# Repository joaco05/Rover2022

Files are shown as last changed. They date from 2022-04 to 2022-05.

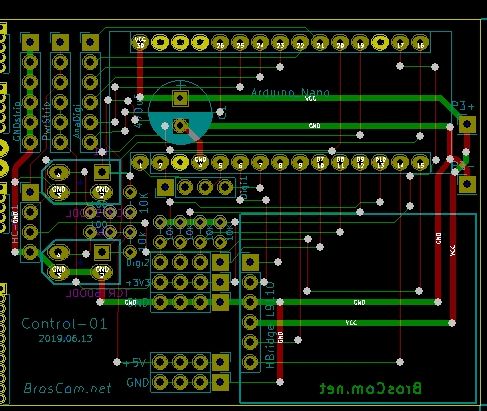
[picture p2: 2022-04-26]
Electronica/ControlPCBs.jpg

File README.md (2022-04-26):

# Rover2022
Rover para clases iniciales. Cerrado y compacto para evitar desconexiones y problemas electricos. Basado en placa Controladora PCB BC2019 (Arduino Nano, driver motores, sensor ultrasonico, sensores IR, conectores) Alimentacion 2 x 3,7V (alimentacion del driver de motores, independiente de Arduino)<br><br>
<b>Printer 3D</b>
Se imprime sin soportes, altura 0,20 o 0,25. Solo las ruedas quedan mejor en modo VASE

<br><br>
<b>ARMADO</b>
El pack de baterias debe ubicarse lo mas adelante posible. Los soportes de motor deberan ir justo despues del borde curvo del chassis, de manera tal que el eje del motor quede al menos 10mm detras del borde.
Esto apunta a que el centro de gravedad se desplace mas cerca de los ejes permitiendo una mejor traccion y evitando patinada de ruedas.

capture_001_20042022_145945

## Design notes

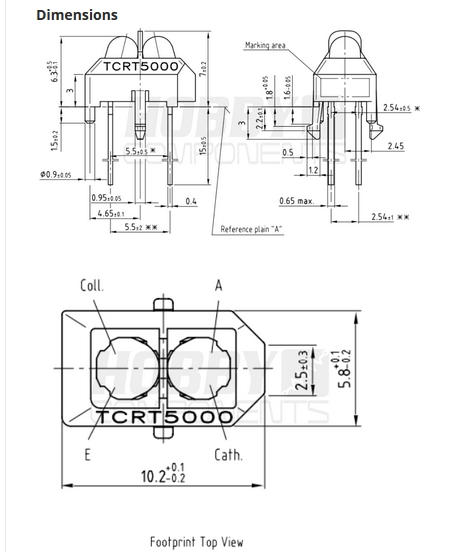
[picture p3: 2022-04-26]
Electronica/VistasTCRT500.jpg

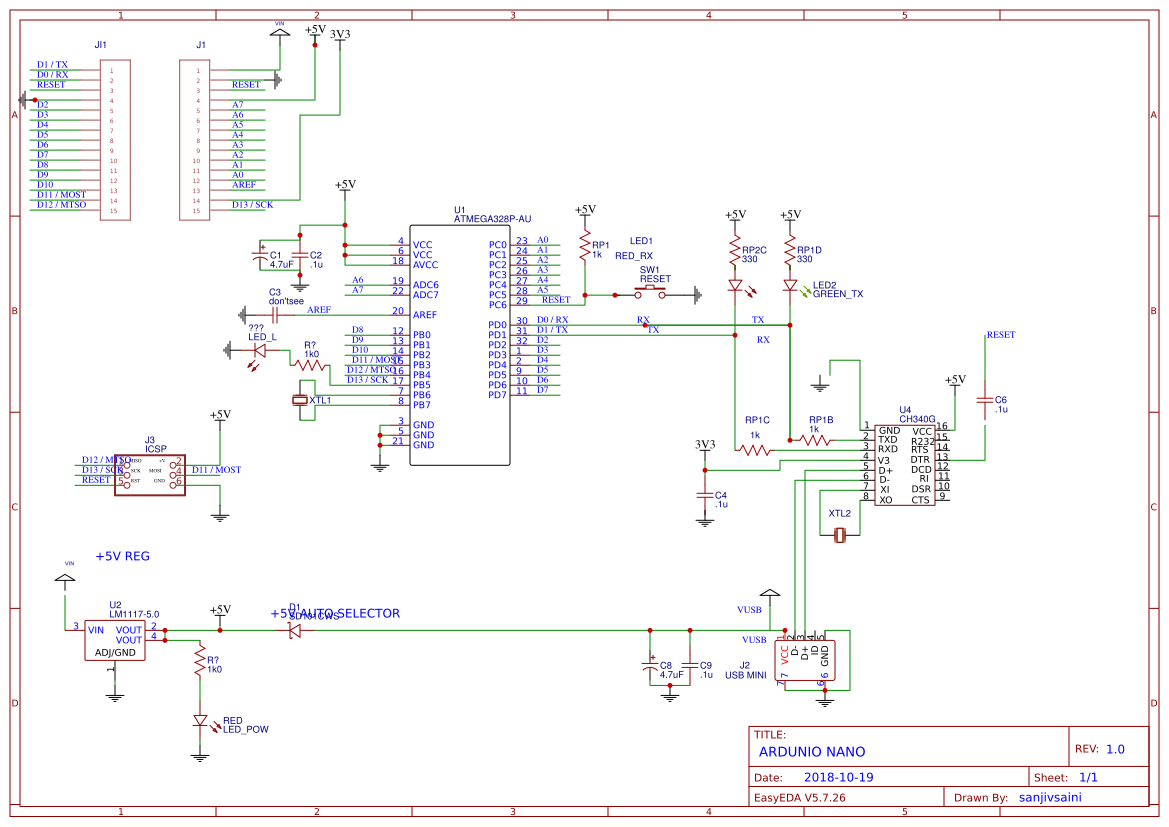
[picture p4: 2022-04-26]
Electronica/ArduinoNanoSch.png

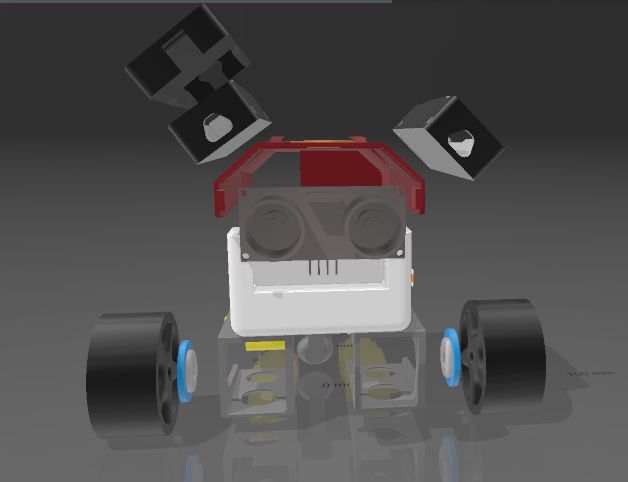
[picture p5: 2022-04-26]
Despiece/capture_002_17042022_132444.jpg

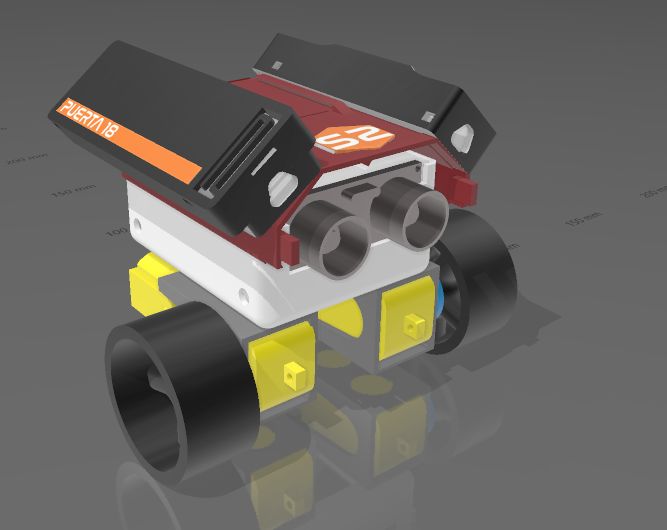
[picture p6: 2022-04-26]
Despiece/capture_001_20042022_145945.jpg

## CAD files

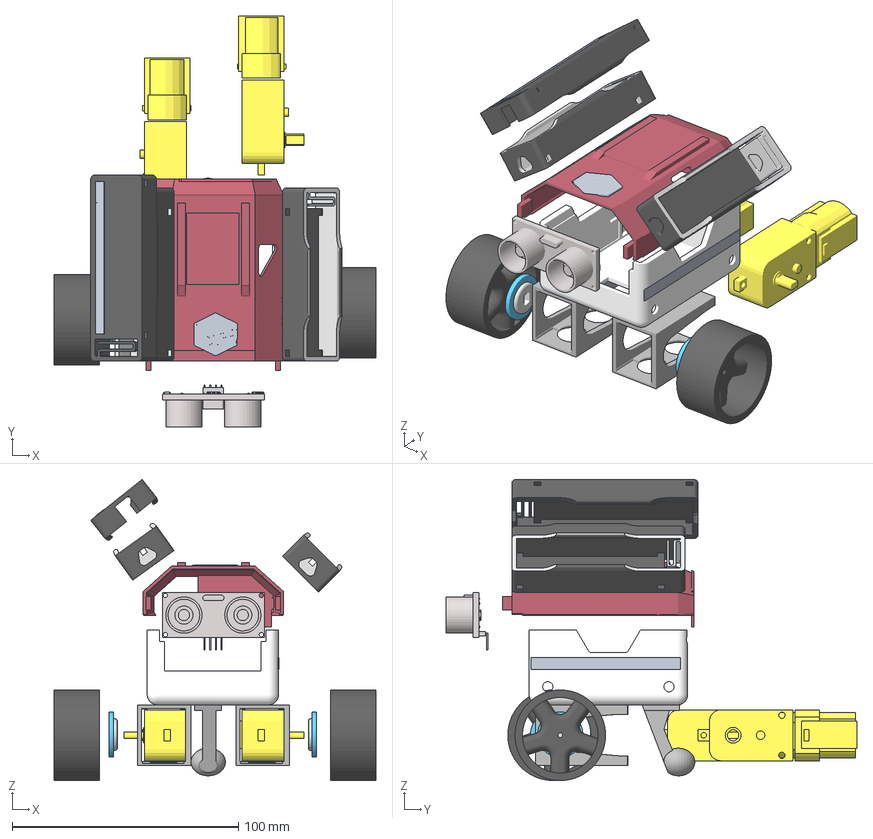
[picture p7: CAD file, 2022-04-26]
3D/SMARSRover2022exploded.3mf
142.1 x 181.5 x 133.0 mm

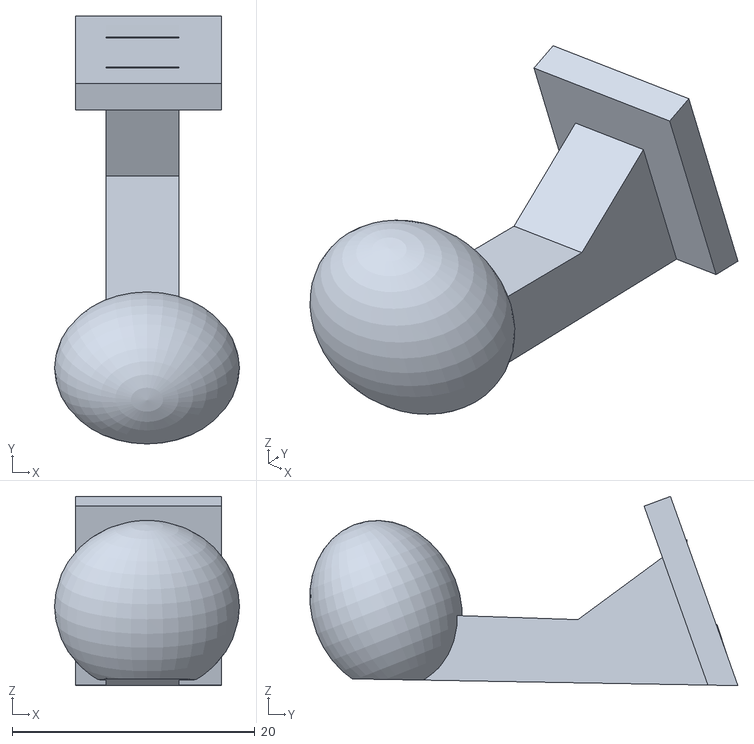
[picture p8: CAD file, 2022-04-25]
3D/STL/PatinCola2.stl
15.2 x 35.3 x 15.6

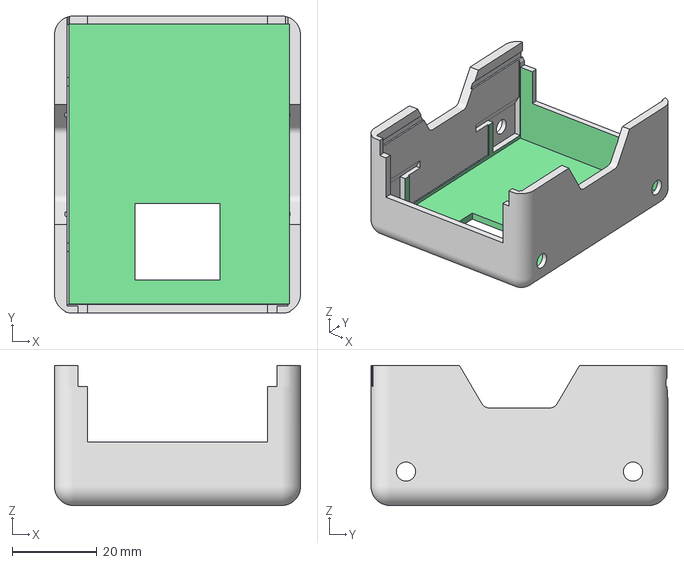
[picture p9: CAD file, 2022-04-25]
3D/2022chassis.3mf
58.0 x 70.0 x 33.0 mm

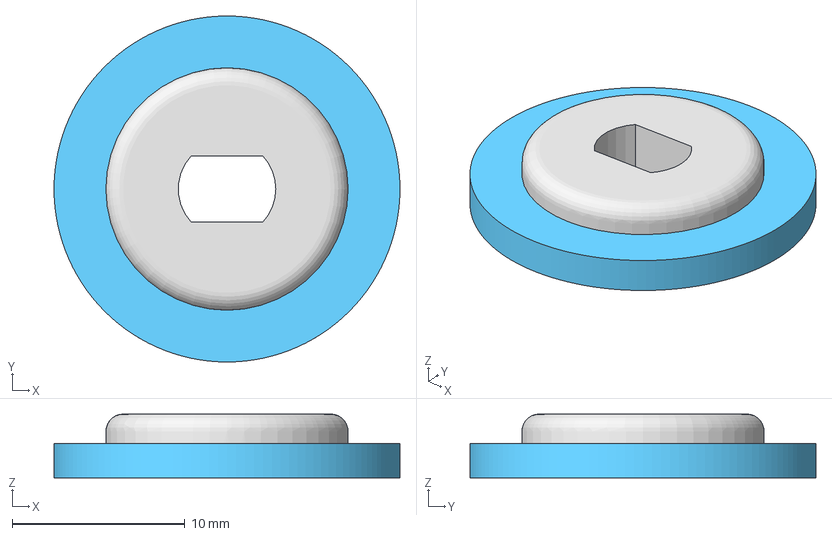
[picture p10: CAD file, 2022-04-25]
3D/TT_Motor_Hub.3mf
20.0 x 20.0 x 3.70 mm

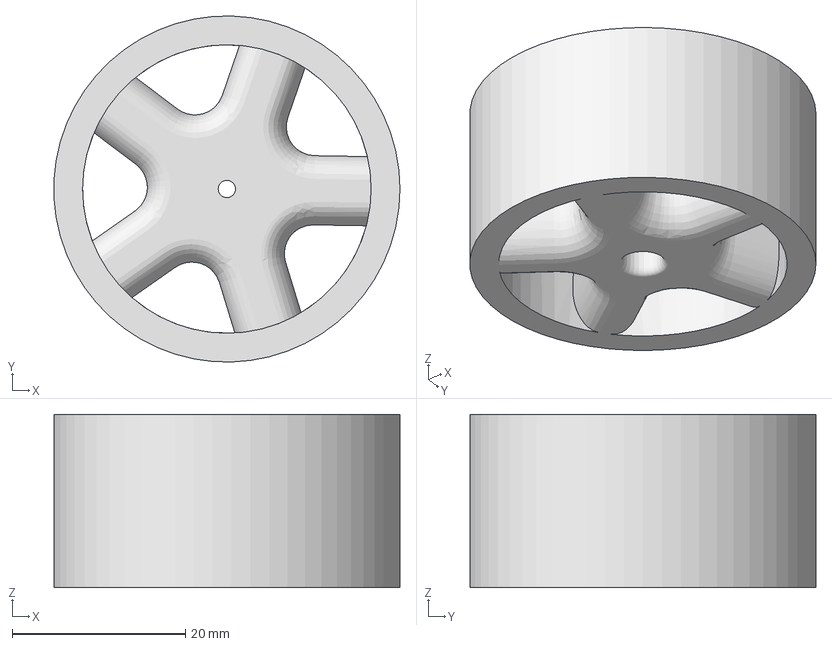
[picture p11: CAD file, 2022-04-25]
3D/Wheel_Rim_40x20mm.3mf
40.0 x 40.0 x 20.0 mm

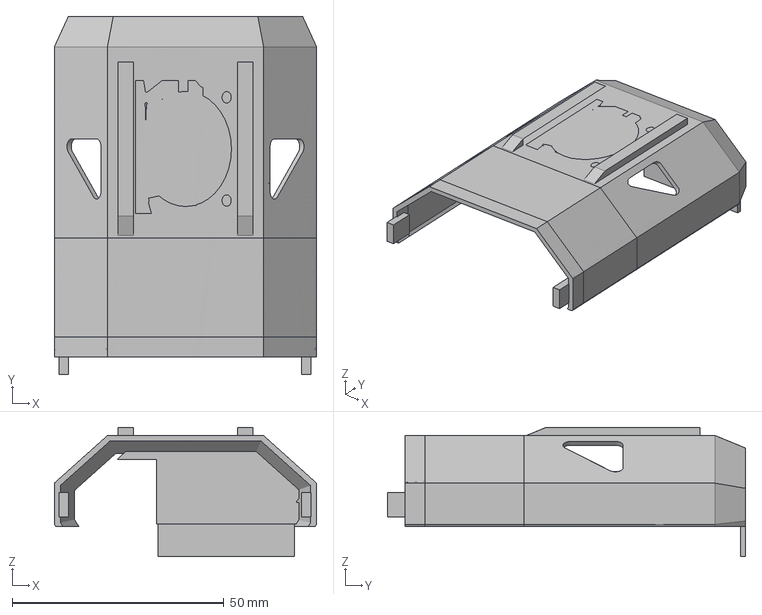
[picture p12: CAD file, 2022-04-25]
3D/SMARSRoverCabina2022a.3mf
62.0 x 84.6 x 30.6 mm

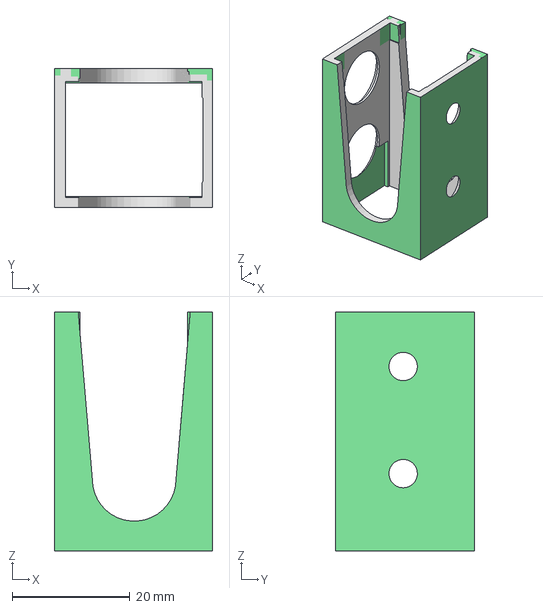
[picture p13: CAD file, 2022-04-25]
3D/2022MotorMount.3mf
26.9 x 23.6 x 40.6 mm

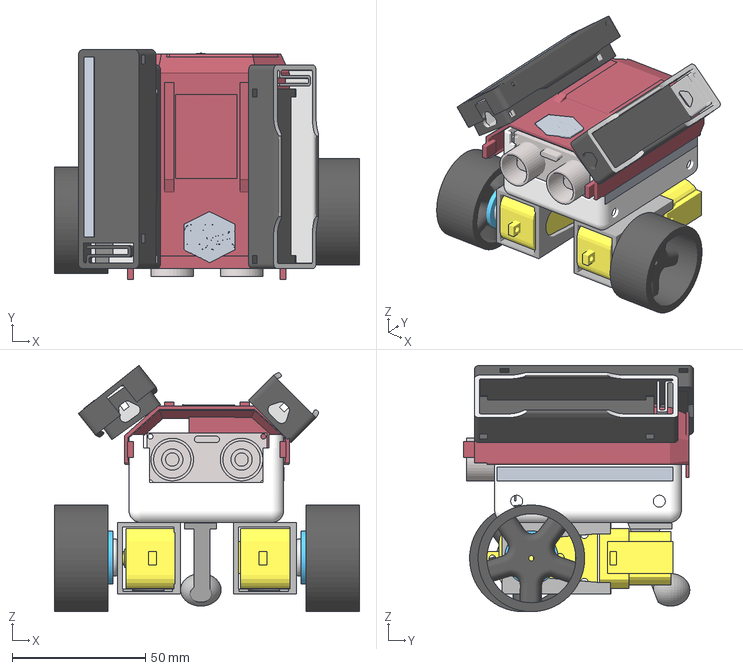
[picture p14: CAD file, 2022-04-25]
3D/SMARSRover2022.3mf
114.4 x 86.3 x 92.4 mm

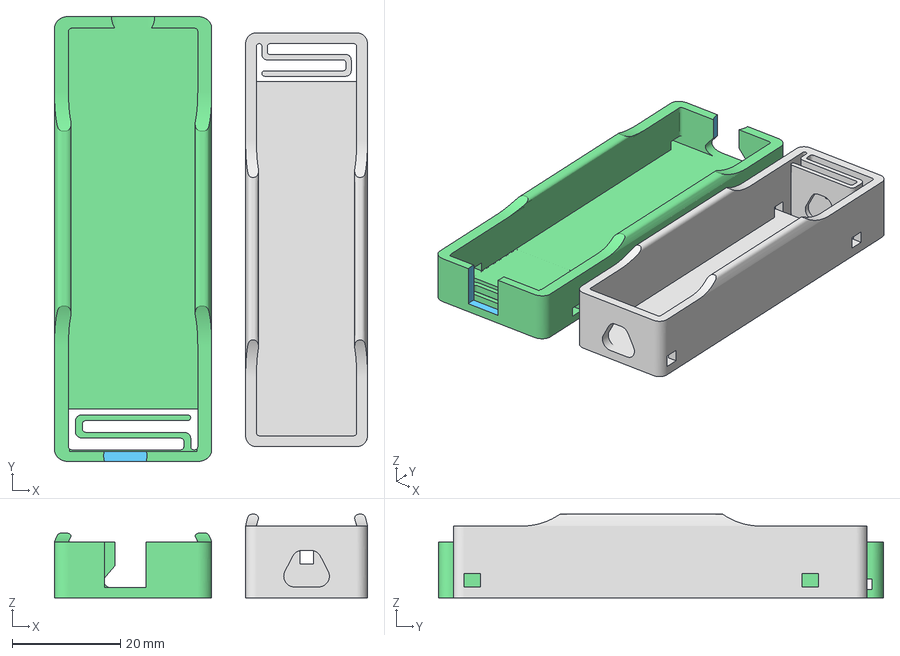
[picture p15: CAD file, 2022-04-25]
3D/18650_X1.3mf
57.9 x 82.3 x 15.5 mm

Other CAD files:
3D/STL/18650_X1.stl
3D/STL/2022MotorMount.stl
3D/STL/2022chassis.stl
3D/STL/SMARSRoverCabina2022a.stl
3D/STL/TT_Motor_Hub.stl
3D/STL/Wheel_Rim_40x20mm.stl

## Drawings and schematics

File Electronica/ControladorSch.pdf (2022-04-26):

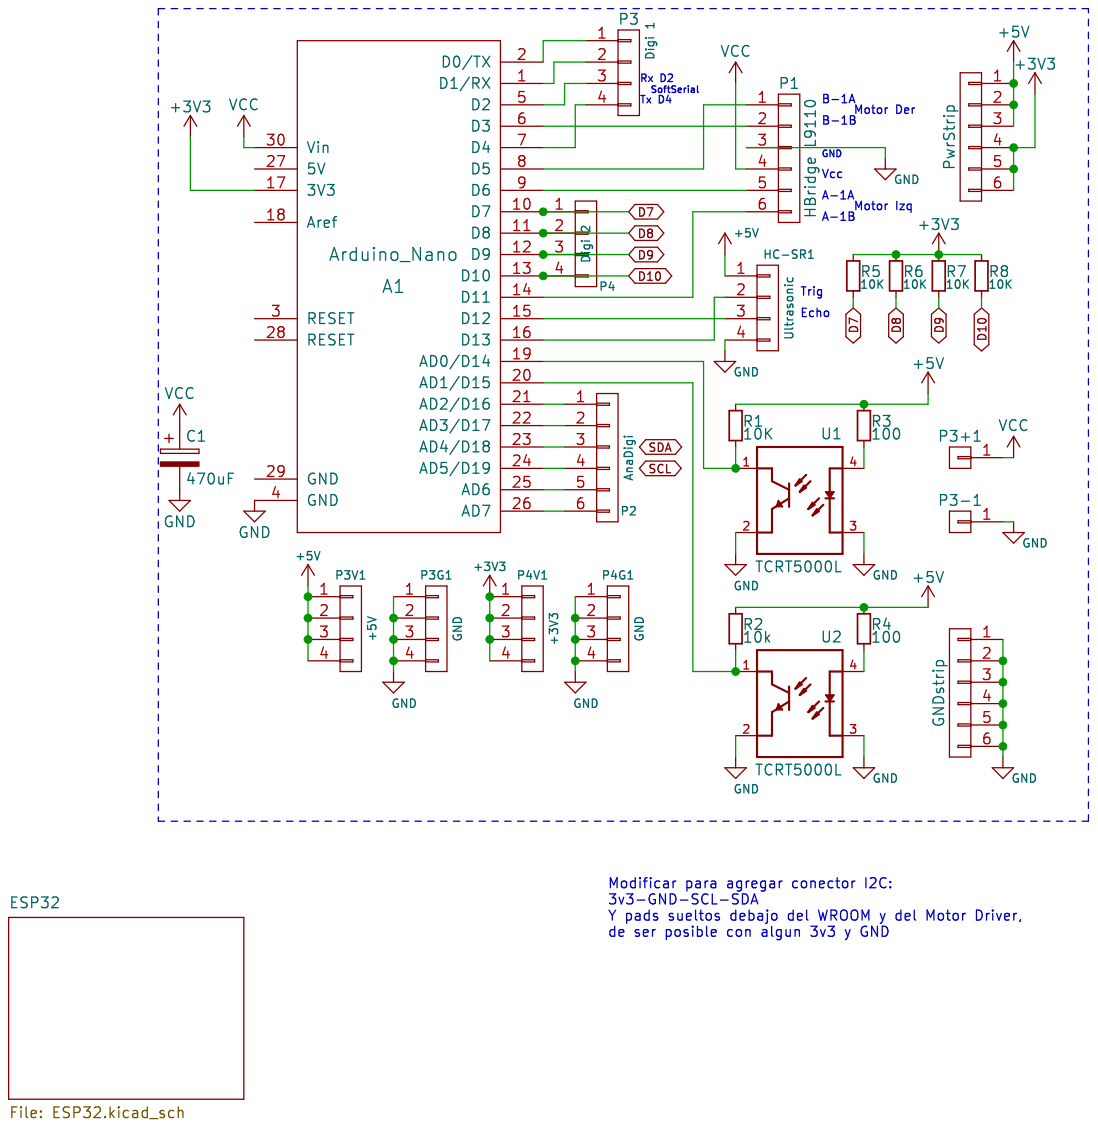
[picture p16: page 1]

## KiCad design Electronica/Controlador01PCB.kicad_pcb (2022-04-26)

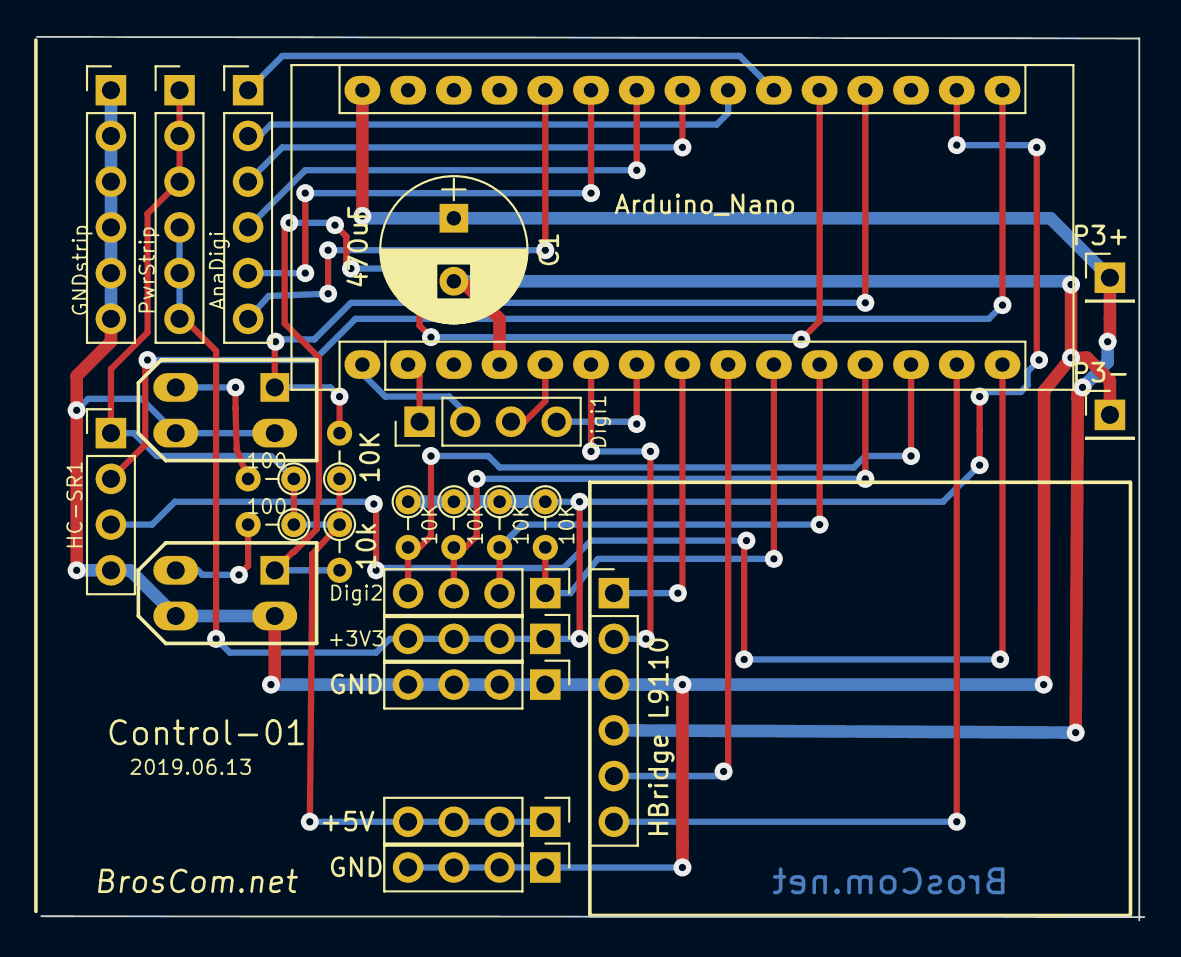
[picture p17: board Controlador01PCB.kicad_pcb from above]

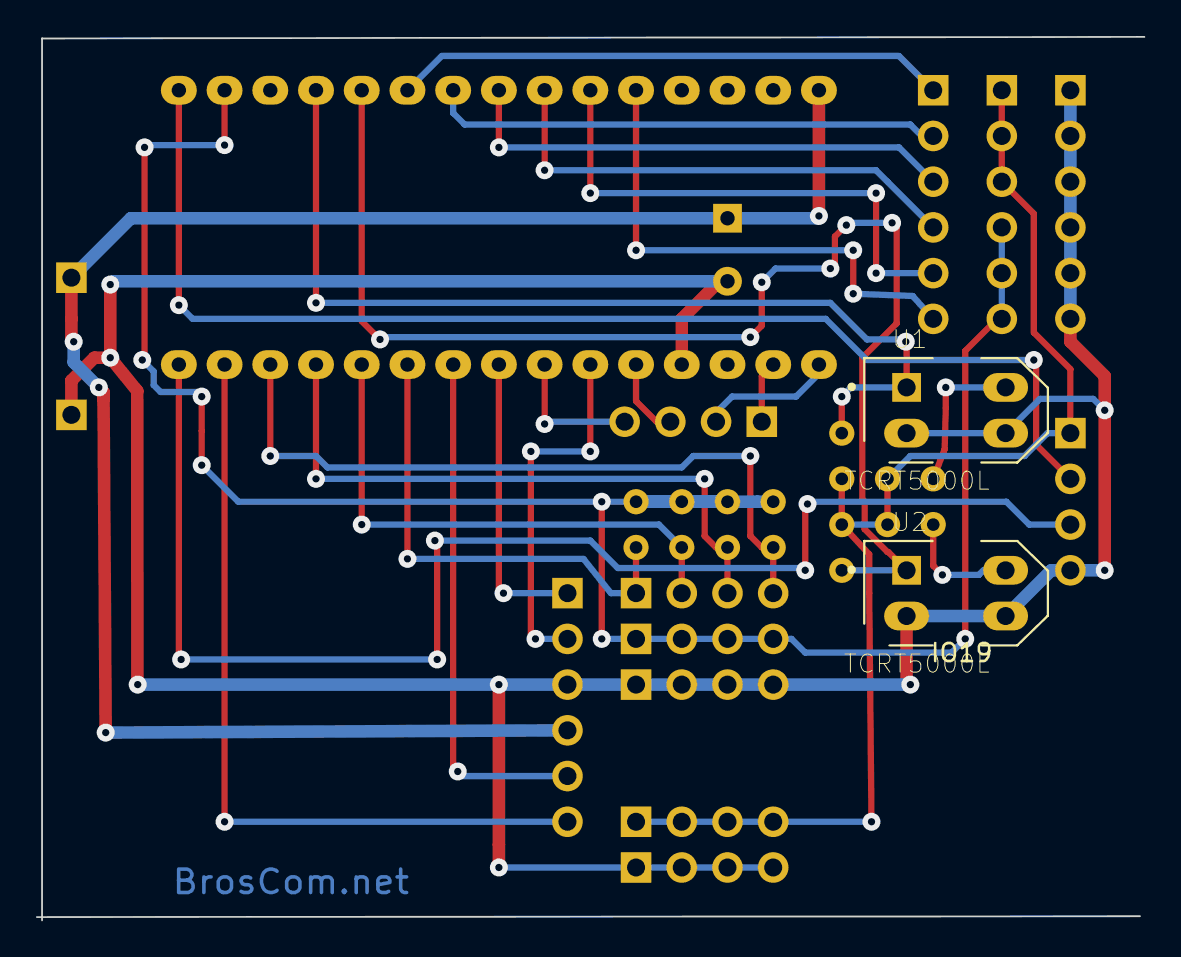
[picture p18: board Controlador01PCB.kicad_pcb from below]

Board: 2 copper layers, 61.5 x 49.1 mm, 25 parts (2 on the bottom side), 28 nets.

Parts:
A1: Arduino_Nano
C1: 470uF; CP_Radial_D8.0mm_P3.50mm
GNDstrip1: GNDstrip; Pin_Header_Straight_1x06_Pitch2.54mm
HC-SR1: Ultrasonic; Pin_Header_Straight_1x04_Pitch2.54mm
P1: HBridge L9110; Pin_Header_Straight_1x06_Pitch2.54mm
P2: AnaDigi; Pin_Header_Straight_1x06_Pitch2.54mm
P3: Digi1; Pin_Header_Straight_1x04_Pitch2.54mm
P3+, P3-: CONN_01X01; Pin_Header_Straight_1x01_Pitch2.54mm
P3G1, P4G1: GND; Pin_Header_Straight_1x04_Pitch2.54mm
P3V1: +5V; Pin_Header_Straight_1x04_Pitch2.54mm
P4: Digi2; Pin_Header_Straight_1x04_Pitch2.54mm
P4V1: +3V3; Pin_Header_Straight_1x04_Pitch2.54mm
PwrStrip1: PwrStrip; Pin_Header_Straight_1x06_Pitch2.54mm
R1, R5, R6, R7, R8: 10K; R_Axial_DIN0204_L3.6mm_D1.6mm_P2.54mm_Vertical
R2: 10k; R_Axial_DIN0204_L3.6mm_D1.6mm_P2.54mm_Vertical
R3, R4: 100; R_Axial_DIN0204_L3.6mm_D1.6mm_P2.54mm_Vertical
U1, U2: TCRT5000L; XDCR_TCRT5000L

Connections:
+3V3: A1.17, P4V1.1, P4V1.2, P4V1.3, P4V1.4, PwrStrip1.4, PwrStrip1.5, PwrStrip1.6, R5.1, R6.1, R7.1, R8.1
+5V: HC-SR1.1, P3V1.1, P3V1.2, P3V1.3, P3V1.4, PwrStrip1.1, PwrStrip1.2, PwrStrip1.3, R1.1, R2.1, R3.1, R4.1
D7: A1.10, P4.1, R5.2
D8: A1.11, P4.2, R6.2
D9: A1.12, P4.3, R7.2
D10: A1.13, P4.4, R8.2
GND: A1.4, C1.2, GNDstrip1.1, GNDstrip1.2, GNDstrip1.3, GNDstrip1.4, GNDstrip1.5, GNDstrip1.6, HC-SR1.4, P1.3, P3-.1, P3G1.1, P3G1.2, P3G1.3, P3G1.4, P4G1.1, P4G1.2, P4G1.3, P4G1.4, U1.2, U1.3, U2.2, U2.3
unnamed: A1.1, P3.2
unnamed: A1.2, P3.1
unnamed: A1.5, P3.3
unnamed: A1.6, P1.2
unnamed: A1.7, P3.4
unnamed: A1.8, P1.1
unnamed: A1.9, P1.5
unnamed: A1.14, P1.6
unnamed: A1.15, HC-SR1.3
unnamed: A1.16, HC-SR1.2
unnamed: A1.19, R1.2, U1.1
unnamed: A1.20, R2.2, U2.1
unnamed: A1.21, P2.1
unnamed: A1.22, P2.2
unnamed: A1.23, P2.3
unnamed: A1.24, P2.4
unnamed: A1.25, P2.5
unnamed: A1.26, P2.6
unnamed: R3.2, U1.4
unnamed: R4.2, U2.4
VCC: A1.30, C1.1, P1.4, P3+.1

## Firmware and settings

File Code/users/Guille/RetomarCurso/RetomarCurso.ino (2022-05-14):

// Initialize
String vers = "RetomarCurso";

int PWM1   = 6; // Pin Motor 1  (Izq)    PWM1 = ValM1  , PoM1= HIGH => avanza
int PoM1 = 11;   // Pin Motor 1 (Izq)  PWM1 = HIGH  , PoM1= ValM1 => retrocede
int PWM2   = 5; // Pin Motor 2
int PoM2 = 3;   // Pin Motor 2  (Der)
int ValMax1, ValMax2, ValM1, ValM2;
int BackFwdDer,BackFwdIzq;
int BajoTrig = 6; // TRIG Ultrasonido bajo
int BajoEcho = 8;  // ECHO  ultrasonido bajo
int x, y;
int i = 1;     // increment
//  int LED=13;   NO usar,  PIN 13 es para motor (PWM)
long Dis; 
int dist = 0;


int Direccion = 0;
int PasosDesvio = 0;

int Giro90Grados = 500;
int TiempoEsperaEsquive = 4; //segundos
bool FlagPuedeRetomarCurso = true;
int SegsEspera = 0;
bool FlagMirarAlFrente = false;

void setup()
{

  // Seteo Constantes por tipo Rover (ver Codez)
  //    rover_rojo();
    rover_negro();
  //rover_Sab();
  //rover_DC();
  
  pinMode(PWM1,  OUTPUT);
  pinMode(PoM1,   OUTPUT);
  pinMode(PWM2, OUTPUT);
  pinMode(PoM2, OUTPUT);
  pinMode(BajoTrig, OUTPUT);
  pinMode(BajoEcho, INPUT);
  
  Serial.begin(9600);         // Inicializo canal de comunicaciones
  Serial.println("Start");
  Dis=distancia(BajoTrig,BajoEcho);
  Serial.print("Version: "); Serial.println(vers);
  Serial.print("Rover: "); Serial.print(Dis);
  delay(2000);//Para dar tiempo luego de programarlo /conectar bateria
}//setup


// Main program
void loop()
{
 //Test();
 
  Avanza(100);
  Serial.println("Avanza");
  Serial.println(Direccion);
  dist = distancia(BajoTrig,BajoEcho);
  if(dist<13){
    Serial.println(dist);
    Serial.println("Esquiva");
    Esquiva();
    SegsEspera = (millis()/1000) + TiempoEsperaEsquive;
    FlagMirarAlFrente = true;
    Para();
    delay(500);
  }
 
  if(millis()/1000 < SegsEspera)
  {
    FlagPuedeRetomarCurso = false;
  }
  else
  {
    FlagPuedeRetomarCurso = true;
  }
  
  if(FlagPuedeRetomarCurso)
  {
   RetomarCurso();    
  }
}//endloop

//*****************************  Funciones ******************************

void RetomarCurso(){
  Serial.println("RetomarCurso");
  if(FlagMirarAlFrente == true){
    GirarADireccion(0);
  FlagMirarAlFrente = false;
  }
  else
  {
  if (PasosDesvio > 1000 && Direccion != -1){
    GirarADireccion(-1);
  }
  if(PasosDesvio < -1000 && Direccion != 1){
    GirarADireccion(1);
  }
  if(PasosDesvio < 200 && PasosDesvio > -200 && Direccion != 0){
    GirarADireccion(0);
  }
  }
}//endRetomarCurso

void GirarADireccion(int dir){
  if (dir == -1 && Direccion == 0)
  {
    GiroIzq(Giro90Grados);
    Para();
    delay(500);
  }
  else if (dir == -1 && Direccion == 1){
    GiroIzq(Giro90Grados);
    Para();
    delay(500);
    GiroIzq(Giro90Grados);
    Para();
    delay(500);
  }
  else if(dir == 0 && Direccion == -1){
    GiroDer(Giro90Grados);
    Para();
    delay(500);
  }
  else if(dir == 0 && Direccion == 1){
    GiroIzq(Giro90Grados);
    Para();
    delay(500);
  }
  else if(dir == 1 && Direccion == 0){
    GiroDer(Giro90Grados);
    Para();
    delay(500);
  }
  else if(dir == 1 && Direccion == -1){
    GiroDer(Giro90Grados);
    Para();
    delay(500);
    GiroDer(Giro90Grados);
    Para();
    delay(500);
  }
}//endGirarDireccion

void Esquiva(){
  Para();
  delay(500);
  if (random(2) == 0){
    GiroDer(Giro90Grados);
    Para();
  }
  else{
    GiroIzq(Giro90Grados);
    Para();
  }
  delay(500);
}//endEsquiva

void Test(){
   Avanza(2500);
   Para();
   delay(500);
   GiroDer(Giro90Grados);
   Para();
   delay(500);
   GiroDer(Giro90Grados);
   Para();
   delay(500);
   delay(3000);
}//endTest

void Arranca(){// Potencia maxima para vencer inercia del motor
  analogWrite(PoM1, BackFwdIzq) ;  // High en rover
  analogWrite(PWM1, ValMax1) ;
  analogWrite(PoM2, BackFwdDer) ;   // High en rover
  analogWrite(PWM2, ValMax2);
  delay(80);

}
void Avanza(int Dly) {
  analogWrite(PoM1, BackFwdIzq) ;  // High en rover
  analogWrite(PWM1, ValM1) ;
  analogWrite(PoM2, BackFwdDer) ;   // High en rover
  analogWrite(PWM2, ValM2);
  delay(Dly);

  if(Direccion == 1)
  {
    PasosDesvio = PasosDesvio + Dly;
  }
  if(Direccion == -1)
  {
    PasosDesvio = PasosDesvio - Dly;
  }
}
void Retrocede(int Dly) {
  analogWrite(PoM1, ValMax1) ;
  analogWrite(PWM1, BackFwdIzq) ;
  analogWrite(PoM2, ValMax2) ;
  analogWrite(PWM2, BackFwdDer) ;
  delay(50);
  analogWrite(PoM1, ValM1) ;
  analogWrite(PWM1, BackFwdIzq) ;
  analogWrite(PoM2, ValM2-30) ;
  analogWrite(PWM2, BackFwdDer) ;
  delay(Dly);
}
void Para() {
  digitalWrite(PoM1, LOW) ;
  digitalWrite(PoM2, LOW) ;
  digitalWrite(PWM1, LOW) ;
  digitalWrite(PWM2, LOW) ;
  delay(10);
}
void GiroDer(int Dly) {
  Para();
  delay(500);
  if(Direccion !=1){
    
  analogWrite(PoM1, BackFwdIzq) ;   //izq avanza
  analogWrite(PWM1, ValMax1) ;
  analogWrite(PoM2, ValMax2) ;
  analogWrite(PWM2,BackFwdDer) ;
  delay(50);
  
  analogWrite(PoM1, BackFwdIzq) ;   //izq avanza
  analogWrite(PWM1, ValM1) ;
  analogWrite(PoM2, ValM2) ;
  analogWrite(PWM2,BackFwdDer);
  delay(Dly);
  }

  if (Direccion == 0)
  {
    Direccion = 1;
  }
  else if (Direccion == -1)
  {
    Direccion = 0;
  }
  else if (Direccion == 1)
  {
    GiroIzq(Giro90Grados);
    delay(250);
    GiroIzq(Giro90Grados);
    delay(250);
  }
  
}
void GiroIzq(int Dly) {
  Para();
  delay(500);
  if(Direccion != -1){
    
  analogWrite(PoM1, ValMax1) ;   //izq retrocede
  analogWrite(PWM1, BackFwdIzq) ;
  analogWrite(PoM2, BackFwdDer) ;
  analogWrite(PWM2,ValMax2 ) ;
  delay(50);
 
  analogWrite(PoM1, ValM1) ;   //Motor izq retrocede
  analogWrite(PWM1, BackFwdIzq) ;
  analogWrite(PoM2, BackFwdDer) ;
  analogWrite(PWM2, ValM2);
  delay(Dly);
  }

  if (Direccion == 0)
  {
    Direccion = -1;
  }
  else if (Direccion == 1)
  {
    Direccion = 0;
  }
  else if (Direccion == -1)
  {
    GiroDer(Giro90Grados);
    delay(250);
    GiroDer(Giro90Grados);
    delay(250);
  }
}


void ArcoDer() {
  analogWrite(PoM1, HIGH) ;   //Motor izq retrocede
  analogWrite(PWM1, ValM1) ;
  analogWrite(PoM2, LOW) ;
  analogWrite(PWM2, LOW) ;
}

void ArcoIzq() {
  analogWrite(PoM1, 0) ;   //Motor izq
  analogWrite(PWM1, 0) ;
  analogWrite(PoM2, 255) ;
  analogWrite(PWM2, ValM2) ;
}

long distancia(int Trig, int Echo) { //Mide la distancia y la guarda en "cm"
  long resultado; long Tiempo_us;
  digitalWrite(Trig, LOW);
  delayMicroseconds(2);
  digitalWrite(Trig, HIGH);
  delayMicroseconds(10);
  digitalWrite(Trig, LOW);
  Tiempo_us = pulseIn(Echo, HIGH, 4060);
  resultado = Tiempo_us / 58;
  delay(100); // Verificar
  if (Tiempo_us == 0) {
    resultado = 199;
  }
  return resultado;
} // distancia

// End.

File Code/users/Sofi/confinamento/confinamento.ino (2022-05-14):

 String vers = "Sensor IR vers 0.1  2019May22";
int TipoRover=2;// 1-Rojo 2-Negro
int sensorIzqPin = A0;    // 
int sensorDerPin = A1;    // 
int sensorIzqValue = 0;    // 
int sensorDerValue = 0;    // 
int ledPin = 13;      //
int BackFwdDer,BackFwdIzq;
int TEsqIzq = 1; // Tiempo de esquiva Giro izquierdo
int TEsqDer = 1; // Tiempo de esquiva Giro derecho
int DistDetect = 1; //Distancia minima //para esquivar lo cambie estaba en 15
int TPorPasos = 0; // Cant de Tiempo (mS) a avanzar por cada paso programado (depende de cada bot)//lo cambie estaba en 250
int PasosPorCm = 0; // Cant de pasos por cada CM medido en el seteo del juego
int ValMax1 = 200; //Valor maximo motor izquierdo
int ValMax2 = 200; //Valor maximo motor derecho
int ValM1 = 200; // Potencia Motor Izq
int ValM2 = 200; // Potencia Motor Der // cambie la potencia,estaba en 175
//******************************************

///seguir avanzando en blanco hasta encontrar negro

//++++++++++++++++++++++++++++++++++++++++++
int Pasos = 0;//Cant de pasos seteados (se decrementa por cada Avance/Giro)
//boolean goUp = true ; // Used to detect acceleration or deceleration
int PWM1   = 6; // Pin Motor 1  (Izq)    PWM1 = ValM1  , PoM1= HIGH => avanza
int PoM1 = 11;   // Pin Motor 1 (Izq)  PWM1 = HIGH  , PoM1= ValM1 => retrocede
int PWM2   = 5; // Pin Motor 2  
int PoM2 = 3;   // Pin Motor 2  (Der)
int BajoTrig = 10 ; // TRIG Ultrasonido bajo
int BajoEcho = 9;  // ECHO  ultrasonido bajo
int PinBotonA = 7; int BotonA;
int x,y;
int i = 1;     // increment 
int Obs = 0; 
void setup() {
  
  // Seteo Constantes por tipo Rover (ver Codez)
  rover_rojo_mesa();
  //rover_rojo();
  //rover_negro();
  //rover_Sab();
  //rover_DC();
  
  pinMode(ledPin, OUTPUT);
  Serial.begin(9600);
  delay (50);
  Serial.println("Start");
  Serial.print("Version: "); Serial.println(vers);
  delay (50);

  Avanza(1000); 
  GiroDer(1000);
  Para();delay(300);
  GiroIzq(1000);
  Para();delay(300);
}//setup

void loop() {
  // 
  sensorDerValue = analogRead(sensorDerPin);
  Serial.print(sensorDerValue);
  Serial.print(",");
  sensorIzqValue = analogRead(sensorIzqPin);
  Serial.println(sensorIzqValue);
  delay(200);
  
//seguidor de lineas negras

if ((sensorIzqValue > 100) and (sensorDerValue > 100)){Serial.println("go");
Avanza(100);}

if ( (sensorIzqValue < 100)and (sensorDerValue > 100) ) { Serial.println ("turn right");
GiroDer(950);
Avanza(100);
}

if ( (sensorDerValue < 100) and (sensorIzqValue > 100) ){ Serial.println ("turn left");
GiroDer(950);
Avanza(100);
}

if((sensorIzqValue < 100) and (sensorDerValue < 100)){Serial.println("lost.");
delay(200);
Para();
}

}//loop

void ArcoDer(int Dly) {
  analogWrite(PoM1, HIGH) ;  // High en rover
  analogWrite(PWM1, ValM1) ;
  analogWrite(PoM2, 0) ;   // High en rover
  analogWrite(PWM2, 0);
  delay(Dly); 
}

void ArcoIzq(int Dly) {
  analogWrite(PoM1, 0) ;  // High en rover
  analogWrite(PWM1, 0) ;
  analogWrite(PoM2, HIGH) ;   // High en rover
  analogWrite(PWM2, ValM2);
  delay(Dly);
}
void Para(){
    delay (100);
    digitalWrite(PoM1, LOW) ;   // Both motor with same polarity
    digitalWrite(PoM2, LOW) ;  
    digitalWrite(PWM1, LOW) ;   // Both motor with same polarity
    digitalWrite(PWM2, LOW) ;   
    delay(10);
}


void Avanza(int Dly) {
  analogWrite(PoM1, HIGH) ;  // High en rover
  analogWrite(PWM1, ValM1) ;
  analogWrite(PoM2, HIGH) ;   // High en rover
  analogWrite(PWM2, ValM2);
  delay(Dly);
  
}
void GiroDer(int Dly) {
  analogWrite(PoM1, BackFwdIzq) ;   //izq avanza
  analogWrite(PWM1, ValMax1) ;
  analogWrite(PoM2, ValMax2) ;
  analogWrite(PWM2,BackFwdDer ) ;
  delay(50);
  
  analogWrite(PoM1, BackFwdIzq) ;   //izq avanza
  analogWrite(PWM1, ValM1-10) ;
  analogWrite(PoM2, ValM2-10) ;
  analogWrite(PWM2,BackFwdDer );
  delay(Dly);
}
void GiroIzq(int Dly) {
  analogWrite(PoM1, ValMax1) ;   //izq retrocede
  analogWrite(PWM1, BackFwdIzq) ;
  analogWrite(PoM2, BackFwdDer) ;
  analogWrite(PWM2,ValMax2 ) ;
  delay(50);
 
  analogWrite(PoM1, ValM1) ;   //Motor izq retrocede
  analogWrite(PWM1, BackFwdIzq) ;
  analogWrite(PoM2, BackFwdDer) ;
  analogWrite(PWM2, ValM2);
  delay(Dly);
}
